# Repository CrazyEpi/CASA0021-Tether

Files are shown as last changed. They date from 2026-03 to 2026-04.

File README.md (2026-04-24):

# Tether 🚴

**A connected cycling companion for motivation, awareness and safety.**

Tether combines a handlebar-mounted ambient device with a companion mobile app to deliver real-time ride feedback, social comparison, and emergency signalling — without requiring cyclists to look at their phone.

<figure>
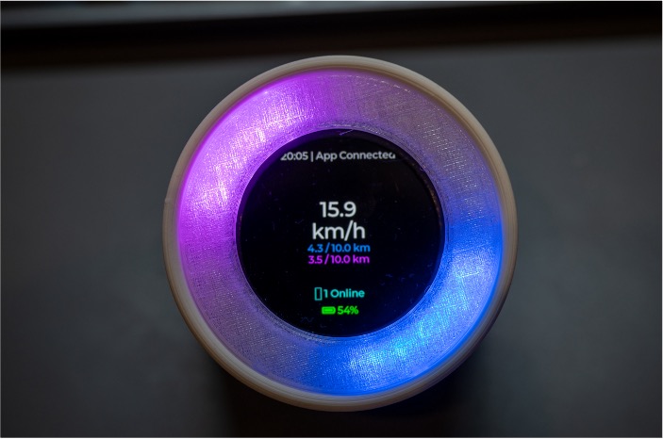
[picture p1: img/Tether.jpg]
Final Tether prototype mounted on handlebars
  
  <figcaption><strong>Figure 1.</strong> Final prototype mounted on handlebars, showing the 1.75" AMOLED display and 24-LED NeoPixel ring.</figcaption>
</figure>

---

## What does Tether do?

Tether solves a simple but important problem: cyclists need information that is easy to understand without becoming distracted. Existing apps like Strava require you to look at your phone. Cycling computers still demand focused attention. Tether moves that information to your handlebars in a form you can read in a glance.

The system has three core functions:

**Ride awareness** — The 24-LED NeoPixel ring fills progressively as you approach your distance goal. Speed, time, connection status and battery are shown on the AMOLED display. All feedback is designed to be readable peripherally, without stopping your ride.

**Social connection** — In friend mode, the LED ring splits into two arcs: blue for your progress, purple for your friend's. Both arcs update in real time via Firebase cloud sync, so you can feel connected to a riding partner even when riding separately.

**Safety signalling** — A three-second physical hold on the device button sends an SOS alert via BLE to the app and onwards to the cloud, notifying your contacts without you needing to unlock your phone.

---

## Why is Tether useful?

Most cycling technology is built around screen interaction — which is incompatible with the physical demands of riding. Tether is the only system we are aware of that combines ambient ride feedback, concurrent social presence, and physical emergency signalling in a single handlebar-mounted device.

Compared to the Beeline Velo 2 (£99.99) — the closest commercial comparator — Tether adds real-time friend comparison and active SOS signalling at a similar price point. The honest gap is battery durability and weather sealing, which are the primary targets for the next development cycle.

---

## Getting started

You will need:
- A compatible Android or iOS smartphone
- The Tether mobile app (Flutter)
- The assembled Tether hardware device
- Bluetooth enabled on your phone

### Phase 1 — Hardware assembly

**Components required:**

| Component | Purpose |
|---|---|
| Waveshare ESP32-S3-Touch-AMOLED-1.75 | Main controller + display |
| NeoPixel Ring — 24 x 5050 RGB LED | Ambient progress ring |
| 1000mAh 3.7V LiPo Battery | Power supply |
| 1.25mm Ultra-Slim 2-pin Cable | Battery connector |
| 3D-printed enclosure | Handlebar housing |

**3D-printed enclosure:**

The enclosure design file is included in the `/3dprint/` directory of this repository as a Fusion 360 file (`.f3d`). Open it in Autodesk Fusion 360 to export as STL before slicing. Print settings that worked for us:

- Material: PLA
- Layer height: 0.2mm
- Infill: 20%
- Supports: required for the internal nut holders

The enclosure went through four revision cycles. The current version (v4) includes a rotary interlock for handlebar attachment, a friction-based screen locker to prevent display rotation under vibration, and a diffuser cover over the LED ring. The handlebar mount uses rubber bands for rapid field adjustment during the prototype phase — loop them through the two side slots and around your handlebar.

**Assembly steps:**

1. Connect the 24-LED NeoPixel Ring to the ESP32-S3 board — Data pin to GPIO 16, with 3.3V/5V and GND connected appropriately.
2. Connect the battery to the board using the 1.25mm pitch 2-pin cable.
3. Seat all components inside the 3D-printed enclosure, matching the three copper nuts to the three holders. Insert the Dupont connector into the rectangular slot.
4. Attach the diffuser cover over the LED ring — press firmly to seat it evenly around the full circumference to minimise light bleed in direct sunlight.
5. Mount the enclosure to your handlebar using rubber bands through the side slots, or use the rotary interlock if your handlebar diameter is compatible.

> **Note:** The diffuser cover fit is intentionally tight — uneven seating causes light bleed between LED segments in bright conditions. This is a known limitation being addressed in the next enclosure revision.

### Phase 2 — ESP32 firmware setup (Arduino IDE)

**Board configuration:**

- Board: `ESP32S3 Dev Module`
- PSRAM: `OPI PSRAM` (enable in Tools menu if required by your board variant)

**Required libraries:**

| Library | Purpose |
|---|---|
| GFX_Library_for_Arduino | Graphics driver for the CO5300 display |
| ESP32_IO_Expander | Driver for the TCA9554 IO expansion chip |
| lvgl (v8.4.0) | Core LVGL graphics library |
| SensorLib | Driver for PCF85063, QMI8658, and CST9217 sensors |
| XPowersLib | Driver for the AXP2101 power management chip |
| Mylibrary | Custom macro definitions for development board pins |
| lv_conf.h | LVGL configuration file |

Install all libraries via Arduino IDE Library Manager or place them in your Arduino `libraries` folder. Flash the firmware to the ESP32-S3 via USB.

### Phase 3 — Mobile app setup (Flutter)

1. Ensure the Flutter SDK is installed on your machine ([flutter.dev](https://flutter.dev)).
2. Clone this repository and navigate to the `/app` directory.
3. Run `flutter pub get` to fetch all Dart package dependencies.
4. Connect your Android or iOS device and run `flutter run`.

The app will scan for the BLE device named `BikeTracker_E` automatically when you start a ride.

### Phase 4 — Firebase backend setup

Tether uses Firebase for three functions: user authentication, real-time ride data sync between riders, and managing each user's friend circle for social comparison and SOS contact routing.

**Services used:**
- **Firebase Authentication** — email/password sign-in for all app users
- **Cloud Firestore** — real-time database storing user profiles, ride data, and live ride state; used by the app's `onSnapshot` listeners to push a friend's updated distance to the handlebar device within seconds
- **Friend circle management** — each user document in Firestore stores a list of followed friends; the app queries this to populate the leaderboard, social feed, and live split-ring comparison

**Setup steps:**

1. Create a Firebase project at [console.firebase.google.com](https://console.firebase.google.com).
2. Enable **Firebase Authentication** (email/password provider).
3. Enable **Cloud Firestore** — select region `europe-west2`.
4. Download the `google-services.json` (Android) or `GoogleService-Info.plist` (iOS) from your Firebase project settings and place it in:
   - Android: `/app/android/app/google-services.json`
   - iOS: `/app/ios/Runner/GoogleService-Info.plist`
5. Apply the following Firestore security rules:

```
rules_version = '2';
service cloud.firestore {
  match /databases/{database}/documents {
    match /users/{userId} {
      allow read: if request.auth != null;
      allow write: if request.auth.uid == userId;
      match /{document=**} {
        allow read: if request.auth != null;
        allow write: if request.auth.uid == userId;
      }
    }
    match /rides/{rideId} {
      allow read, write: if request.auth != null;
    }
  }
}
```

6. Run `flutter pub get` after placing the config files, then rebuild the app.

> **Note:** The friend circle is managed through Firestore — users follow each other by storing friend UIDs in their user document. The app resolves friend live-ride state from Firestore in real time and writes it to the handlebar device via BLE on each update.

---

## BLE communication reference

The device and app communicate over a single BLE service.

**Device name:** `BikeTracker_E`  
**Primary service UUID:** `19B10000-E8F2-537E-4F6C-D104768A1214`

| Characteristic | UUID Suffix | Direction | Data type | Payload |
|---|---|---|---|---|
| Live Metrics | `...0001` | App → ESP32 | String (UTF-8) | `"Speed,MyDist,FriendDist,FriendGoal"` e.g. `15.5,2.5,3.1,10.0` |
| Target Goal | `...0002` | App → ESP32 | Float32 (LE) | Absolute target distance in km |
| Time Sync | `...0003` | App → ESP32 | String (UTF-8) | `"HH:MM"` — syncs phone time to display |
| Social State | `...0004` | App → ESP32 | Int32 (LE) | Number of online friends; triggers split-ring mode if > 0 |
| SOS Alert | `...0005` | ESP32 → App | Byte (Notify) | `0x01` triggered / `0x00` cleared |
| Social Pulse | `...0006` | App → ESP32 | Byte | `0x01` — triggers 2-second cyan breathing animation |

The SOS characteristic uses BLE Notify (device pushes to app) rather than polling, ensuring zero-latency emergency broadcast regardless of app foreground state.

---

## LED states reference

| Mode | Colour | Trigger |
|---|---|---|
| Solo riding | Single blue arc | No friends online |
| Friend mode | Split blue/purple arc | Friend online and riding |
| SOS emergency | Full ring solid red | SOS button held 3 seconds |
| Social pulse | Cyan breathing | Friend milestone event |
| Low speed | Dimmed display | Speed below threshold |

---

## App screens

The Flutter app covers the full ride lifecycle across 8 screens:

- **Home & feed** — activity feed, weekly stats, kudos
- **Live tracking** — real-time GPS map with BLE device connection
- **Goals & route planner** — set distance goals, plan route via Google Maps API
- **Leaderboard** — monthly and all-time rankings with friends
- **Profile** — ride history, stats, follow friends
- **Developer console** — simulate hardware LED states for testing without the physical device

---

## Where to get help

- **GitHub Issues** — [open an issue](../../issues) for bugs or technical problems
- **GitHub Discussions** — [start a discussion](../../discussions) for questions or ideas
- **Email** — contact the team directly at [ucfnuaw@ucl.ac.uk](mailto:ucfnuaw@ucl.ac.uk)

---

## Who maintains and contributes to this project

**Four Gods — Group 4, CASA0021, UCL Bartlett CASA 2025–26**

| Name | Role |
|---|---|
| Gilang Pamungkas | Backend & cloud infrastructure |
| Haoyu Hu | Hardware development, app improvement, testing, video |
| Yidan Gao | Frontend & mobile application |
| Yifei Huang | 3D print & enclosure design |

**Public repository:** [https://github.com/CrazyEpi/CASA0021-Tether](https://github.com/CrazyEpi/CASA0021-Tether)

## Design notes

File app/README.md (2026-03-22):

# GPP Cycling Tracker

UCL CASA0021 — Group 3 · Flutter App

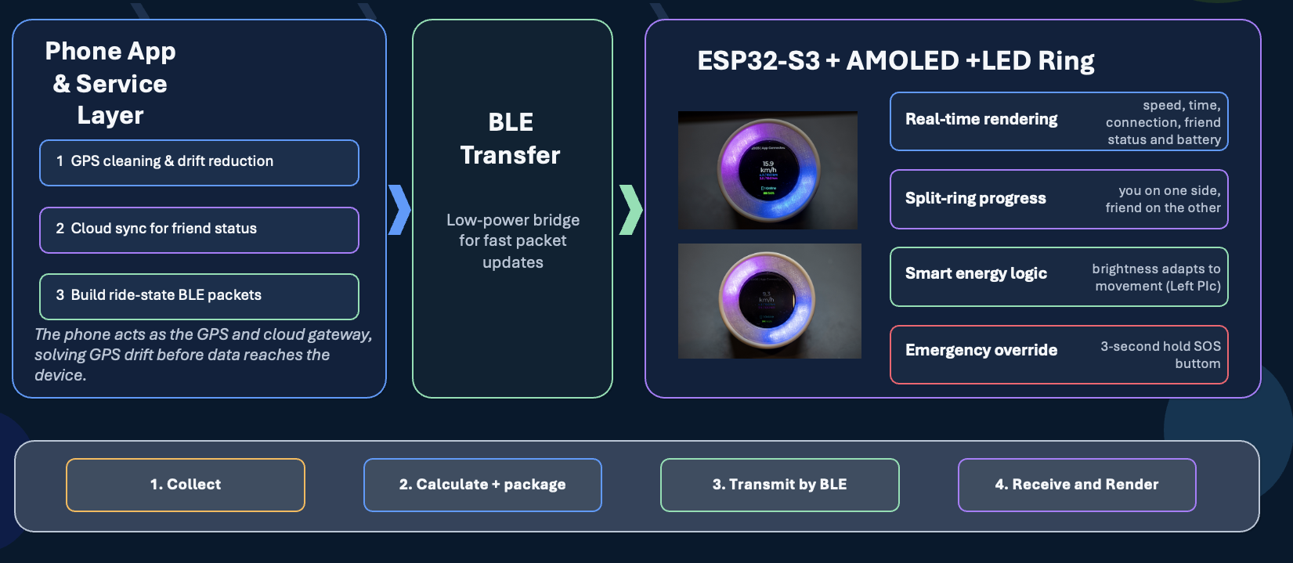
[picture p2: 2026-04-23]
img/diagram.png

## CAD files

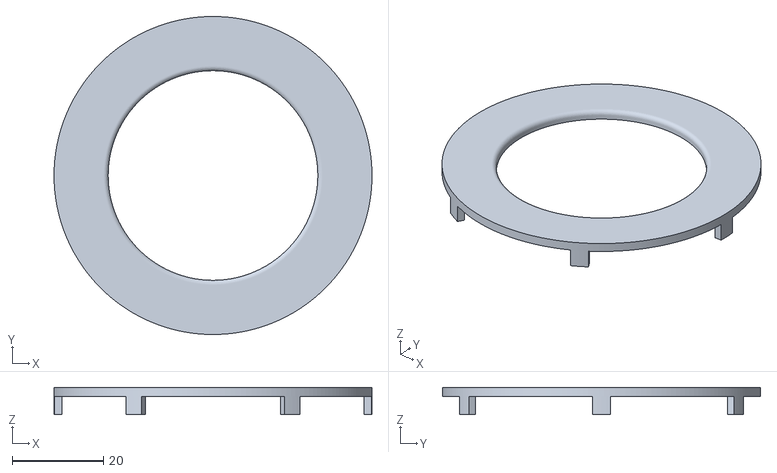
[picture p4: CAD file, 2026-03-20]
3dprint/3Dprint/top.stl
69.8 x 69.8 x 6.00

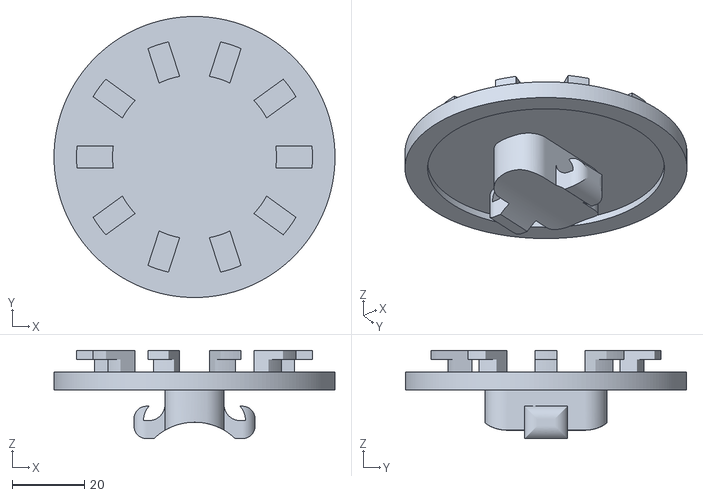
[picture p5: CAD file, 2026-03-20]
3dprint/3dPrint3/bottom.stl
78.0 x 78.0 x 24.5

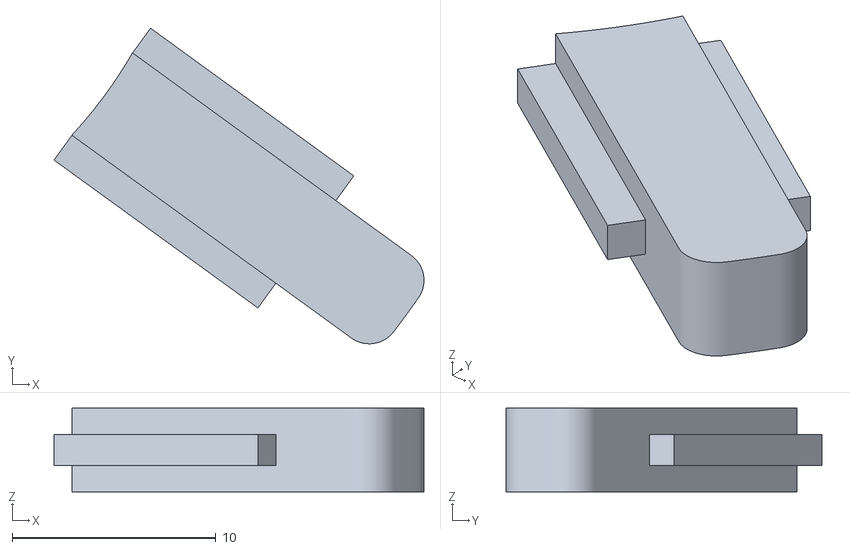
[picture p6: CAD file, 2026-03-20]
3dprint/3dPrint4/buttonLong.stl
18.2 x 15.5 x 4.10

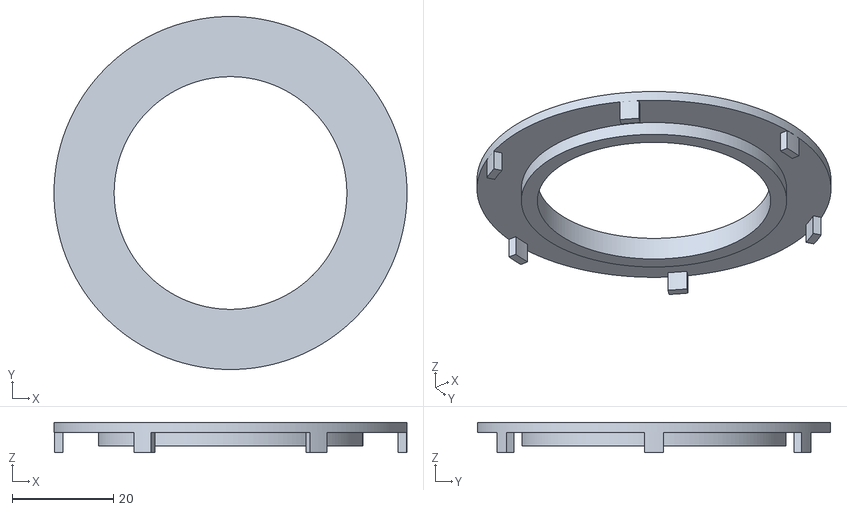
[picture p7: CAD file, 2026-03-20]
3dprint/3dPrint5/top.stl
69.8 x 69.8 x 6.00

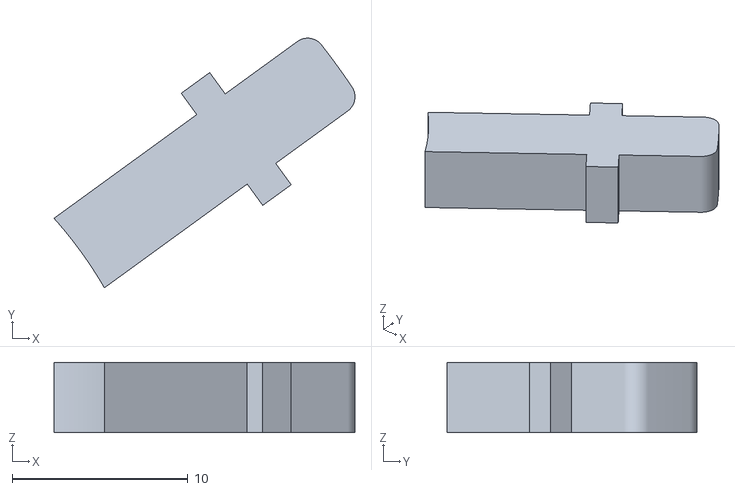
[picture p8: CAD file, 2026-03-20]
3dprint/3Dprint/b.stl
17.1 x 14.2 x 4.00

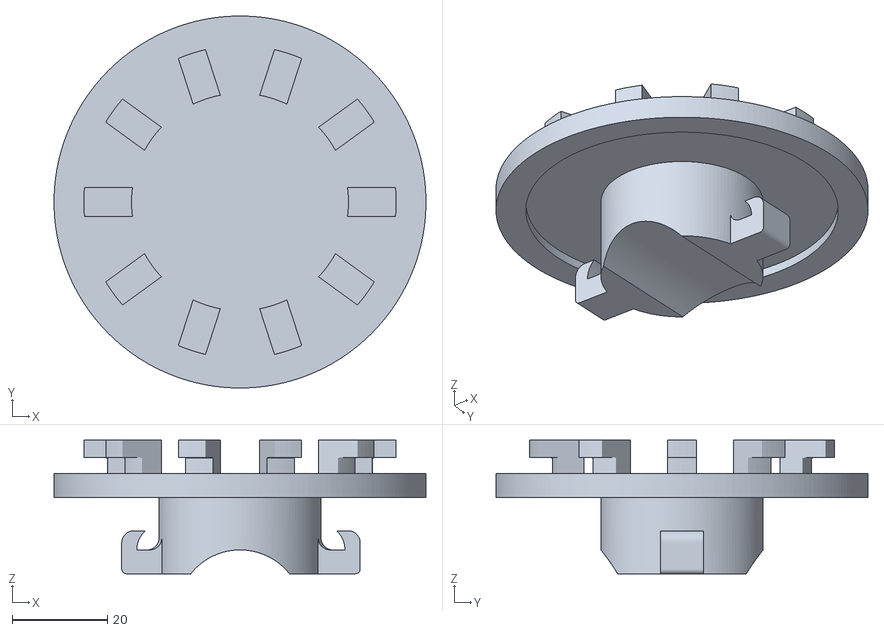
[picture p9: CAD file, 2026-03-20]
3dprint/3dprint2/bottom2.stl
78.0 x 78.0 x 28.0

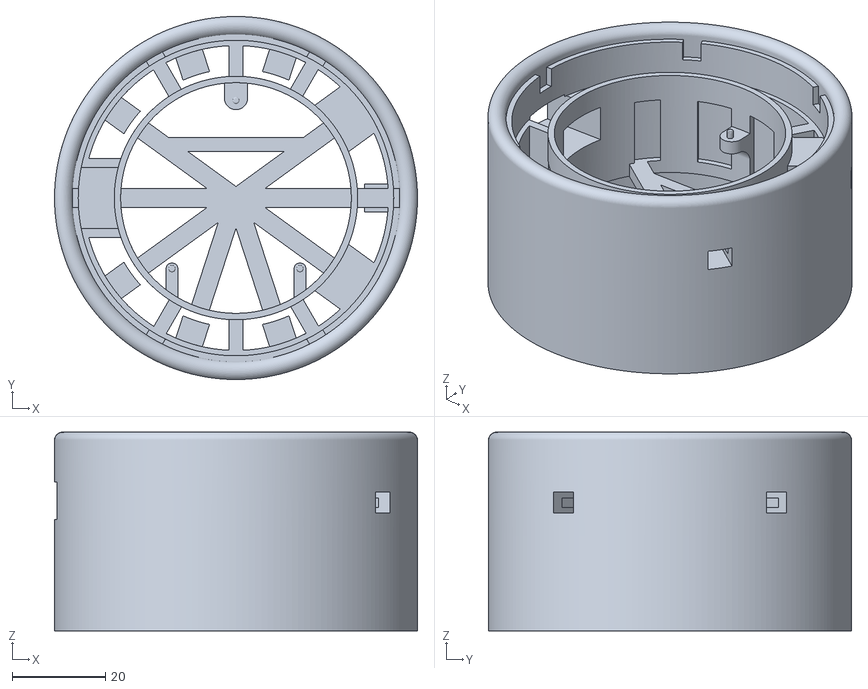
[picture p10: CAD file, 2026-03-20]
3dprint/3dPrint3/case.stl
78.0 x 78.0 x 42.8

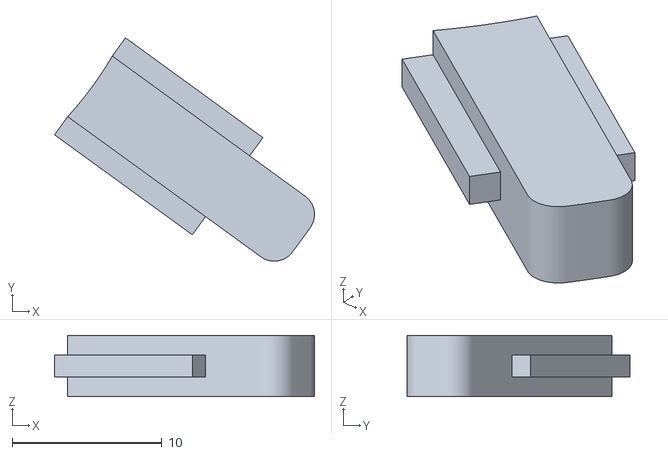
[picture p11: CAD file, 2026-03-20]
3dprint/3dPrint4/button.stl
17.3 x 14.9 x 4.10

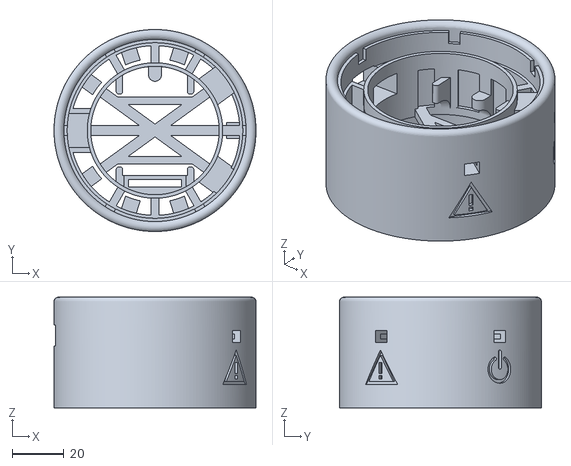
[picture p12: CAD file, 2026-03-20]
3dprint/3dPrint5/case.stl
78.0 x 78.0 x 42.8

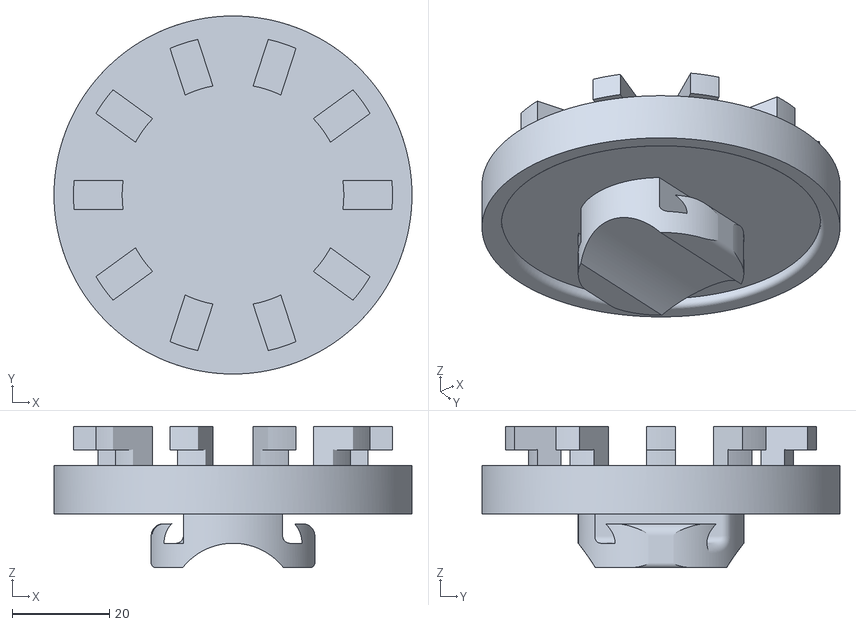
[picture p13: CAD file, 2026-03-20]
3dprint/3Dprint/bottom.stl
73.5 x 73.5 x 29.0

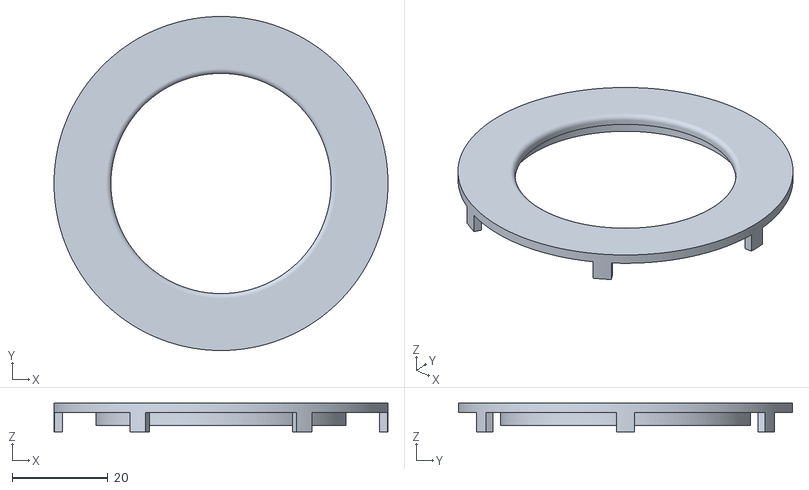
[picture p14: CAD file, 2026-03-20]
3dprint/3dPrint3/top.stl
69.8 x 69.8 x 6.00

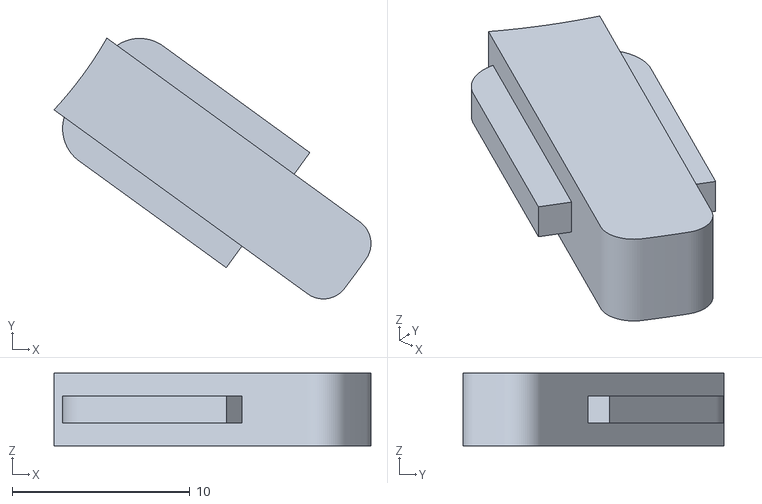
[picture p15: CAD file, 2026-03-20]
3dprint/3dPrint5/button.stl
17.8 x 14.7 x 4.10

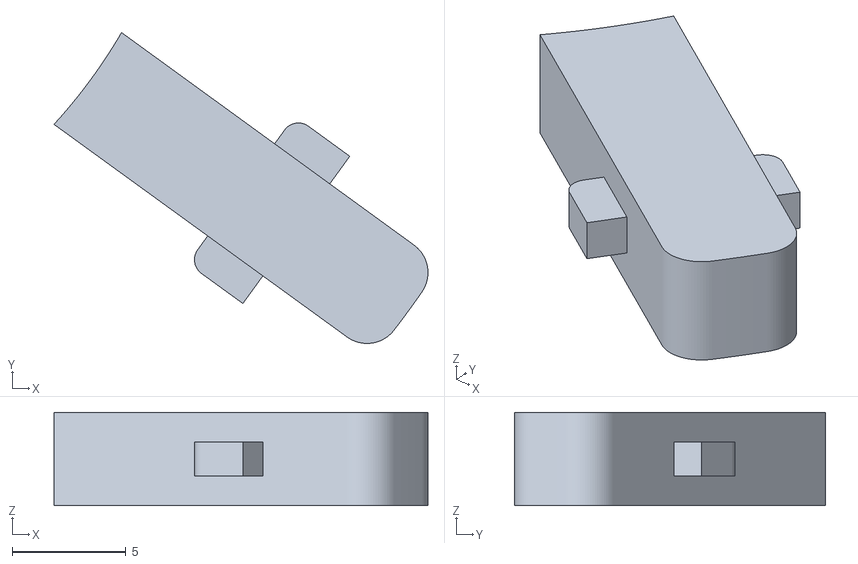
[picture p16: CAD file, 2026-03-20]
3dprint/3dPrint3/button.stl
16.5 x 13.7 x 4.10

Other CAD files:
3dprint/3dprint2/top.stl
3dprint/3dPrint4/case.stl
3dprint/3Dprint/bottomBIG.stl
3dprint/3dprint2/case.stl
3dprint/0021-EnclosurePrototypeTwo.f3d
3dprint/3Dprint/a.stl
3dprint/3Dprint/c.stl
3dprint/3Dprint/case.stl
3dprint/3Dprint/d.stl
3dprint/3Dprint/firstprint.3mf
3dprint/3dPrint5/0021-EnclosurePrototypeFive.f3d.f3d
3dprint/3dPrint5/bottom.stl
3dprint/3dprint2/button.stl
3dprint/CASA0021.f3d

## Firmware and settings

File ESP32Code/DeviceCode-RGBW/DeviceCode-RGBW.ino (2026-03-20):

#include <ArduinoBLE.h>
#include <Adafruit_NeoPixel.h>
#include <lvgl.h>
#include "Arduino_GFX_Library.h"
#include "pin_config.h" 
#include <Wire.h>
#include "XPowersLib.h"
#include "TouchDrvCSTXXX.hpp" 

// Pin Config
#define LED_PIN    16   
#define NUMPIXELS  24   // 24 LED Ring
#define BOOT_PIN   0

// RGBW LED Ring
Adafruit_NeoPixel pixels(NUMPIXELS, LED_PIN, NEO_GRBW + NEO_KHZ800);
XPowersPMU power;
TouchDrvCST92xx touch;

Arduino_DataBus *bus = new Arduino_ESP32QSPI(LCD_CS, LCD_SCLK, LCD_SDIO0, LCD_SDIO1, LCD_SDIO2, LCD_SDIO3);
Arduino_CO5300 *gfx = new Arduino_CO5300(bus, LCD_RESET, 0, LCD_WIDTH, LCD_HEIGHT, 6, 0, 0, 0);

static lv_disp_draw_buf_t draw_buf;
static lv_color_t buf[LCD_WIDTH * LCD_HEIGHT / 10];

// Bluetooth "Service" and "Characteristic" UUID
// Service ID: bluetooth function id for connection
// Characteristic ID: detailed function id for functions like location update
const char* BLE_SERVICE_UUID       = "19B10000-E8F2-537E-4F6C-D104768A1214";
const char* BLE_LOCATION_CHAR_UUID = "19B10001-E8F2-537E-4F6C-D104768A1214"; 
const char* BLE_GOAL_CHAR_UUID     = "19B10002-E8F2-537E-4F6C-D104768A1214"; 
const char* BLE_TIME_CHAR_UUID     = "19B10003-E8F2-537E-4F6C-D104768A1214"; 
const char* BLE_FRIEND_CHAR_UUID   = "19B10004-E8F2-537E-4F6C-D104768A1214"; 
const char* BLE_SOS_CHAR_UUID      = "19B10005-E8F2-537E-4F6C-D104768A1214";
const char* BLE_SOCIAL_CHAR_UUID   = "19B10006-E8F2-537E-4F6C-D104768A1214"; 

BLEService bikeService(BLE_SERVICE_UUID);
BLEStringCharacteristic locationChar(BLE_LOCATION_CHAR_UUID, BLERead | BLEWrite, 64); 
BLEFloatCharacteristic goalChar(BLE_GOAL_CHAR_UUID, BLERead | BLEWrite); 
BLEStringCharacteristic timeChar(BLE_TIME_CHAR_UUID, BLERead | BLEWrite, 10);
BLEIntCharacteristic friendChar(BLE_FRIEND_CHAR_UUID, BLERead | BLEWrite);
BLEByteCharacteristic sosChar(BLE_SOS_CHAR_UUID, BLERead | BLENotify);
BLEByteCharacteristic socialChar(BLE_SOCIAL_CHAR_UUID, BLERead | BLEWrite); 

// default datas
double totalDistanceKm = 0.0;
double targetDistanceKm = 10.0; 
float currentSpeed = 0.0;

double friendDistanceKm = 0.0; 
double friendGoalKm = 10.0;     
float friendProgress = 0.0;     

int onlineFriends = 0;
char currentTime[16] = "--:--"; 
bool isPhoneConnected = false;
unsigned long connectionTimestamp = 0;

bool isScreenOn = true;
bool isEmergency = false;
uint8_t currentScreenBrightness = 90;
int16_t touch_x[5], touch_y[5];

bool isSocialPulsing = false;
unsigned long socialPulseTimestamp = 0;

// LVGL UI Stuff
lv_obj_t *label_speed, *label_dist, *label_gps, *label_friends, *label_battery, *sos_container;

// Screen Renderer
void my_disp_flush(lv_disp_drv_t *disp, const lv_area_t *area, lv_color_t *color_p) {
  uint32_t w = (area->x2 - area->x1 + 1); uint32_t h = (area->y2 - area->y1 + 1);
#if (LV_COLOR_16_SWAP != 0)
  gfx->draw16bitBeRGBBitmap(area->x1, area->y1, (uint16_t *)&color_p->full, w, h);
#else
  gfx->draw16bitRGBBitmap(area->x1, area->y1, (uint16_t *)&color_p->full, w, h);
#endif
  lv_disp_flush_ready(disp);
}

// Touchpad read
void my_touchpad_read(lv_indev_drv_t *indev_driver, lv_indev_data_t *data) {
  uint8_t touched = touch.getPoint(touch_x, touch_y, touch.getSupportTouchPoint());
  if (touched > 0) {
    data->state = LV_INDEV_STATE_PR;
    data->point.x = touch_x[0]; data->point.y = touch_y[0];
  } else {
    data->state = LV_INDEV_STATE_REL;
  }
}

// timer for LVGL refresh
void example_increase_lvgl_tick(void *arg) { lv_tick_inc(2); }

// SOS long press cancel
void sos_clear_event_cb(lv_event_t * e) {
  if (isEmergency) {
    isEmergency = false;
    lv_obj_add_flag(sos_container, LV_OBJ_FLAG_HIDDEN);
    sosChar.writeValue((uint8_t)0);
  }
}

// Initialize UI components
void init_bike_dashboard() {
  lv_obj_set_style_bg_color(lv_scr_act(), lv_color_hex(0x000000), LV_PART_MAIN);

  // speed
  label_speed = lv_label_create(lv_scr_act());
  lv_obj_set_width(label_speed, 300); 
  lv_obj_set_style_text_color(label_speed, lv_color_hex(0xFFFFFF), LV_PART_MAIN);
  lv_obj_set_style_text_font(label_speed, &lv_font_montserrat_48, LV_PART_MAIN); 
  lv_label_set_text(label_speed, "0.0\nkm/h");
  lv_obj_set_style_text_align(label_speed, LV_TEXT_ALIGN_CENTER, LV_PART_MAIN);
  lv_obj_align(label_speed, LV_ALIGN_CENTER, 0, -35); 

  // distance multi-color
  label_dist = lv_label_create(lv_scr_act());
  lv_obj_set_width(label_dist, 300); 
  lv_label_set_recolor(label_dist, true); 
  lv_obj_set_style_text_font(label_dist, &lv_font_montserrat_24, LV_PART_MAIN); 
  lv_label_set_text(label_dist, "#4A90E2 0.0 / 0.0 km#"); 
  lv_obj_set_style_text_align(label_dist, LV_TEXT_ALIGN_CENTER, LV_PART_MAIN);
  lv_obj_align(label_dist, LV_ALIGN_CENTER, 0, 45); 

  // Time + App Status
  label_gps = lv_label_create(lv_scr_act());
  lv_obj_set_width(label_gps, 300); 
  lv_obj_set_style_text_color(label_gps, lv_color_hex(0xAAAAAA), LV_PART_MAIN);
  lv_obj_set_style_text_font(label_gps, &lv_font_montserrat_24, LV_PART_MAIN);
  lv_label_set_text(label_gps, "--:-- | Waiting...");
  lv_obj_set_style_text_align(label_gps, LV_TEXT_ALIGN_CENTER, LV_PART_MAIN);
  lv_obj_align(label_gps, LV_ALIGN_TOP_MID, 0, 30); 

  // Friend Status
  label_friends = lv_label_create(lv_scr_act());
  lv_obj_set_width(label_friends, 300); 
  lv_obj_set_style_text_color(label_friends, lv_color_hex(0x00FFFF), LV_PART_MAIN);
  lv_obj_set_style_text_font(label_friends, &lv_font_montserrat_24, LV_PART_MAIN);
  lv_label_set_text(label_friends, ""); 
  lv_obj_set_style_text_align(label_friends, LV_TEXT_ALIGN_CENTER, LV_PART_MAIN);
  lv_obj_align(label_friends, LV_ALIGN_BOTTOM_MID, 0, -80);
  
  // Battery Info
  label_battery = lv_label_create(lv_scr_act());
  lv_obj_set_width(label_battery, 200); 
  lv_obj_set_style_text_color(label_battery, lv_color_hex(0x00FF00), LV_PART_MAIN);
  lv_obj_set_style_text_font(label_battery, &lv_font_montserrat_24, LV_PART_MAIN);
  lv_label_set_text(label_battery, LV_SYMBOL_BATTERY_FULL " --%");
  lv_obj_set_style_text_align(label_battery, LV_TEXT_ALIGN_CENTER, LV_PART_MAIN);
  lv_obj_align(label_battery, LV_ALIGN_BOTTOM_MID, 0, -40);

  // SOS Red Screen
  sos_container = lv_obj_create(lv_scr_act());
  lv_obj_set_size(sos_container, LCD_WIDTH, LCD_HEIGHT);
  lv_obj_set_style_bg_color(sos_container, lv_color_hex(0xAA0000), 0);
  lv_obj_set_style_border_width(sos_container, 0, 0);
  lv_obj_align(sos_container, LV_ALIGN_CENTER, 0, 0);
  lv_obj_add_flag(sos_container, LV_OBJ_FLAG_CLICKABLE);
  lv_obj_add_flag(sos_container, LV_OBJ_FLAG_HIDDEN);
  lv_obj_add_event_cb(sos_container, sos_clear_event_cb, LV_EVENT_LONG_PRESSED, NULL);

  lv_obj_t *sos_label = lv_label_create(sos_container);
  lv_obj_set_style_text_color(sos_label, lv_color_hex(0xFFFFFF), 0);
  lv_obj_set_style_text_font(sos_label, &lv_font_montserrat_48, 0);
  lv_label_set_text(sos_label, LV_SYMBOL_WARNING "\nSOS");
  lv_obj_set_style_text_align(sos_label, LV_TEXT_ALIGN_CENTER, 0);
  lv_obj_align(sos_label, LV_ALIGN_CENTER, 0, 0);
}

void setup() {
  Serial.begin(115200);
  unsigned long startWait = millis();
  while (!Serial && millis() - startWait < 3000) { delay(10); }

  pinMode(BOOT_PIN, INPUT_PULLUP);

  Wire.begin(IIC_SDA, IIC_SCL);
  if(power.begin(Wire, AXP2101_SLAVE_ADDRESS, IIC_SDA, IIC_SCL)) {
    // Initialize Battery Control
    power.clearIrqStatus(); 
    power.enableBattVoltageMeasure();
    power.enableVbusVoltageMeasure(); 
    power.enableIRQ(XPOWERS_AXP2101_PKEY_SHORT_IRQ); 
  }

  touch.setPins(TP_RESET, TP_INT);
  touch.begin(Wire, 0x5A, IIC_SDA, IIC_SCL);
  touch.setMaxCoordinates(LCD_WIDTH, LCD_HEIGHT);
  touch.setMirrorXY(true, true);

  // Display Setups
  gfx->begin();
  gfx->setBrightness(currentScreenBrightness);
  lv_init();
  lv_disp_draw_buf_init(&draw_buf, buf, NULL, LCD_WIDTH * LCD_HEIGHT / 10);
  
  static lv_disp_drv_t disp_drv;
  lv_disp_drv_init(&disp_drv);
  disp_drv.hor_res = LCD_WIDTH; disp_drv.ver_res = LCD_HEIGHT;
  disp_drv.flush_cb = my_disp_flush; disp_drv.draw_buf = &draw_buf;
  lv_disp_drv_register(&disp_drv);

  static lv_indev_drv_t indev_drv;
  lv_indev_drv_init(&indev_drv);
  indev_drv.type = LV_INDEV_TYPE_POINTER;
  indev_drv.read_cb = my_touchpad_read;
  lv_indev_drv_register(&indev_drv);

  // Start the timer
  const esp_timer_create_args_t lvgl_tick_timer_args = { .callback = &example_increase_lvgl_tick, .name = "lvgl_tick" };
  esp_timer_handle_t lvgl_tick_timer = NULL;
  esp_timer_create(&lvgl_tick_timer_args, &lvgl_tick_timer);
  esp_timer_start_periodic(lvgl_tick_timer, 2000); // 2ms tick

  init_bike_dashboard();
  
  // NeoPixel Settings
  pixels.begin(); pixels.setBrightness(25); pixels.clear(); pixels.show();
  
  // Delay for battery then start bluetooth
  delay(300); 

  if (!BLE.begin()) { while (1); }
  BLE.setLocalName("BikeTracker_E"); 
  BLE.setAdvertisedService(bikeService);
  bikeService.addCharacteristic(locationChar);
  bikeService.addCharacteristic(goalChar);
  bikeService.addCharacteristic(timeChar);
  bikeService.addCharacteristic(friendChar);
  bikeService.addCharacteristic(sosChar); 
  bikeService.addCharacteristic(socialChar);
  BLE.addService(bikeService);
  
  sosChar.writeValue((uint8_t)0); 
  BLE.advertise();
}

void loop() {
  BLEDevice central = BLE.central();
  
  // power button screen off
  power.getIrqStatus();
  if (power.isPekeyShortPressIrq()) {
    isScreenOn = !isScreenOn;
    gfx->setBrightness(isScreenOn ? currentScreenBrightness : 0);
    power.clearIrqStatus();
  }

  // Boot long press SOS
  static unsigned long bootPressTime = 0;
  static bool bootPressed = false;
  
  if (digitalRead(BOOT_PIN) == LOW) {
    if (!bootPressed) {
      bootPressed = true;
      bootPressTime = millis();
    } else {
      if (millis() - bootPressTime > 3000 && !isEmergency) {
        isEmergency = true;
        lv_obj_clear_flag(sos_container, LV_OBJ_FLAG_HIDDEN);
        sosChar.writeValue((uint8_t)1); 
        if (!isScreenOn) { isScreenOn = true; gfx->setBrightness(currentScreenBrightness); }
      }
    }
  } else {
    if (bootPressed) {
      unsigned long pressDuration = millis() - bootPressTime;
      if (isEmergency && pressDuration < 1000) {
        isEmergency = false;
        lv_obj_add_flag(sos_container, LV_OBJ_FLAG_HIDDEN);
        sosChar.writeValue((uint8_t)0);
      }
      bootPressed = false;
    }
  }

  // handle data from app
  if (central && central.connected()) {
    if (!isPhoneConnected) {
      isPhoneConnected = true;
      connectionTimestamp = millis();
    }

    // Sync Distance
    if (goalChar.written()) targetDistanceKm = goalChar.value();
    
    // Sync Time
    if (timeChar.written()) {
      String tStr = timeChar.value(); tStr.trim(); 
      strncpy(currentTime, tStr.c_str(), sizeof(currentTime) - 1);
      currentTime[sizeof(currentTime) - 1] = '\0'; 
    }
    
    // Sync friend number
    if (friendChar.written()) {
      onlineFriends = friendChar.value();
      if (onlineFriends > 0) {
        static char friends_buf[32]; 
        snprintf(friends_buf, sizeof(friends_buf), "👥 %d Online", onlineFriends);
        lv_label_set_text(label_friends, friends_buf);
      } else {
        lv_label_set_text(label_friends, ""); 
      }
    }

    // Parse riding data
    if (locationChar.written()) {
      String locStr = locationChar.value();
      locStr.trim(); 
      
      int c1 = locStr.indexOf(',');
      int c2 = locStr.indexOf(',', c1 + 1);
      int c3 = locStr.indexOf(',', c2 + 1);
      
      if (c1 > 0) {
        currentSpeed = locStr.substring(0, c1).toFloat();
        if (c2 > 0) {
           if (c3 > 0) {
               totalDistanceKm = locStr.substring(c1 + 1, c2).toFloat();
               friendDistanceKm = locStr.substring(c2 + 1, c3).toFloat();
               friendGoalKm = locStr.substring(c3 + 1).toFloat();
               if(friendGoalKm <= 0.1) friendGoalKm = 10.0; 
               friendProgress = friendDistanceKm / friendGoalKm;
           } else {
               totalDistanceKm = locStr.substring(c1 + 1, c2).toFloat();
               friendProgress = locStr.substring(c2 + 1).toFloat();
           }
        } else {
           totalDistanceKm = locStr.substring(c1 + 1).toFloat();
        }
      }
    }

    // Sync social pulse
    if (socialChar.written()) {
      if (socialChar.value() == 0x01) {
        isSocialPulsing = true;
        socialPulseTimestamp = millis();
      }
    }

  } else {
    isPhoneConnected = false;
    currentSpeed = 0.0;
  }

  // UI refresh 10hz
  static unsigned long lastUIUpdate = 0;
  if (millis() - lastUIUpdate > 100) {
    lastUIUpdate = millis();

    static char bat_buf[32];
    static char gps_buf[32];
    static char speed_buf[16];
    static char dist_buf[128]; 

    // Auto brightness
    uint8_t targetBrightness = (currentSpeed >= 10.0) ? 200 : 40; 
    uint8_t ledBrightness = (currentSpeed >= 10.0) ? 50 : 20; 

    if (isScreenOn && currentScreenBrightness != targetBrightness) {
      currentScreenBrightness = targetBrightness;
      gfx->setBrightness(currentScreenBrightness);
    }
    pixels.setBrightness(ledBrightness);

    // Update Battery Percentage
    const char* pwr_icon = LV_SYMBOL_BATTERY_FULL; 
    if (power.isVbusIn()) {
      pwr_icon = power.isCharging() ? LV_SYMBOL_CHARGE : LV_SYMBOL_USB; 
    }

    if (power.isBatteryConnect()) {
      snprintf(bat_buf, sizeof(bat_buf), "%s %d%%", pwr_icon, power.getBatteryPercent());
    } else {
      snprintf(bat_buf, sizeof(bat_buf), "%s NO BAT", pwr_icon);
    }
    lv_label_set_text(label_battery, bat_buf);

    if (isPhoneConnected) {
      snprintf(gps_buf, sizeof(gps_buf), "%s | App Connected", currentTime);
      lv_label_set_text(label_gps, gps_buf);
      
      snprintf(speed_buf, sizeof(speed_buf), "%.1f\nkm/h", currentSpeed);
      lv_label_set_text(label_speed, speed_buf);

      if (onlineFriends == 0) {
        snprintf(dist_buf, sizeof(dist_buf), "#4A90E2 %.1f / %.1f km#", totalDistanceKm, targetDistanceKm);
      } else {
        snprintf(dist_buf, sizeof(dist_buf), "#4A90E2 %.1f / %.1f km#\n#D142F5 %.1f / %.1f km#", 
                 totalDistanceKm, targetDistanceKm, friendDistanceKm, friendGoalKm);
      }
      lv_label_set_text(label_dist, dist_buf);

    } else {
      snprintf(gps_buf, sizeof(gps_buf), "%s | Waiting App...", currentTime);
      lv_label_set_text(label_gps, gps_buf);
      lv_label_set_text(label_speed, "0.0\nkm/h");
      lv_label_set_text(label_dist, "#4A90E2 0.0 / 0.0 km#");
    }
    
    // Light Control Router
    if (isEmergency) {
       if ((millis() / 300) % 2 == 0) pixels.fill(pixels.Color(200, 0, 0, 0));
       else pixels.clear();
       pixels.show();
    } 
    else if (isSocialPulsing) {
       if (millis() - socialPulseTimestamp < 2000) updateLED_Social_Pulse();
       else isSocialPulsing = false; 
    }
    else if (isPhoneConnected) {
       if (millis() - connectionTimestamp < 3000) {
         pixels.fill(pixels.Color(0, 150, 0, 0)); pixels.show();
       } else {
         updateLED_SmartProgress(); 
       }
    } 
    else {
       updateLED_Searching_Yellow();
    }
  }

  lv_timer_handler(); 
  delay(5);
}

// Light Control
void updateLED_SmartProgress() {
  float myProg = totalDistanceKm / targetDistanceKm;
  if (myProg > 1.0) myProg = 1.0;
  if (myProg < 0.0) myProg = 0.0;

  pixels.clear();

  if (onlineFriends == 0) {
    int ledsToLight = round(myProg * NUMPIXELS);
    for (int i = 0; i < NUMPIXELS; i++) {
      if (i < ledsToLight) pixels.setPixelColor(i, pixels.Color(0, 0, 150, 0));
    }
  } else {
    float frProg = friendProgress;
    if (frProg > 1.0) frProg = 1.0;
    if (frProg < 0.0) frProg = 0.0;

    int halfLeds = NUMPIXELS / 2; // 12
    int myLedsToLight = round(myProg * halfLeds);
    int frLedsToLight = round(frProg * halfLeds);

    for (int i = 0; i < halfLeds; i++) {
      if (i < myLedsToLight) pixels.setPixelColor(i, pixels.Color(0, 0, 150, 0));
    }
    for (int i = 0; i < halfLeds; i++) {
      if (i < frLedsToLight) pixels.setPixelColor(i + halfLeds, pixels.Color(150, 0, 150, 0));
    }
  }
  
  pixels.show(); 
}

void updateLED_Searching_Yellow() {
  pixels.fill(pixels.Color(100, 100, 0, 0)); pixels.show();
}

void updateLED_Social_Pulse() {
  unsigned long t = millis() - socialPulseTimestamp;
  float breath = (sin(t / 150.0) + 1.0) / 2.0; 
  uint8_t brightness = 20 + (breath * 80);
  int offset = (t / 50) % NUMPIXELS;

  pixels.clear();
  for (int i = 0; i < NUMPIXELS; i++) {
    if (i == offset || i == (offset + NUMPIXELS/2) % NUMPIXELS) {
      pixels.setPixelColor(i, pixels.Color(0, 0, 0, 0));
    } else {
      pixels.setPixelColor(i, pixels.Color(0, brightness, brightness, 0));
    }
  }
  pixels.show();
}

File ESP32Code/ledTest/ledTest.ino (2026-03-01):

#include <Adafruit_NeoPixel.h>

// LED Settings
#define LED_PIN    6   // LED Pin: 6
#define NUMPIXELS  12  // LED numbers
Adafruit_NeoPixel pixels(NUMPIXELS, LED_PIN, NEO_GRB + NEO_KHZ800);

float targetDistance = 100.0;
float currentDistance = 0.0;

void setup() {
  // baud rate: DO NOT SET TO 9600, it wont work
  Serial.begin(115200);
  while (!Serial) { delay(10); }

  // initialize led
  pixels.begin();
  pixels.clear();
  pixels.show();

  Serial.println("\n=================================");
  Serial.println("LED TEST !!!!!!!!");
  Serial.println("=================================");
  Serial.println("Send command to mimic user scene");
  Serial.println("Input: T+Number = target distance (T100 = 100m)");
  Serial.println("Input D+Number = current distance (D80 = now went 80m)");
  Serial.println("=================================\n");
  
  updateLEDProgress();
}

void loop() {
  if (Serial.available() > 0) {
    String input = Serial.readStringUntil('\n');

    if (input.length() > 1) {
      // take command type
      char command = input.charAt(0);
      float value = input.substring(1).toFloat();

      if (command == 'T' || command == 't') {
        if (value <= 0) {
          Serial.println("distance must > 0");
        } else {
          targetDistance = value;
          Serial.print("target update : ");
          Serial.print(targetDistance);
          Serial.println(" m");
        }
      } 
      else if (command == 'D' || command == 'd') {
        currentDistance = value;
        Serial.print("current distance update: ");
        Serial.print(currentDistance);
        Serial.println(" m");
      } 
      else {
        Serial.println("Unknown command ");
      }

      // update led
      updateLEDProgress();
    }
  }
}

// light control
void updateLEDProgress() {
  // percentage
  float progress = currentDistance / targetDistance;
  
  // frame boundries
  if (progress < 0) progress = 0;
  if (progress > 1.0) progress = 1.0; 

  // lighted led numbers
  int ledsToLight = round(progress * NUMPIXELS);

  Serial.print("Current Progress: ");
  Serial.print(progress * 100, 1);
  Serial.print("%  |  Lighted LED Numbers: ");
  Serial.print(ledsToLight);
  Serial.print(" / ");
  Serial.println(NUMPIXELS);
  Serial.println("---------------------------------");

  // update LED
  pixels.clear();
  for (int i = 0; i < NUMPIXELS; i++) {
    if (i < ledsToLight) {
      // Gree: finished parts
      pixels.setPixelColor(i, pixels.Color(0, 100, 0));
    } else {
      // unfinished parts
      pixels.setPixelColor(i, pixels.Color(0, 0, 0)); 
    }
  }
  pixels.show();
}

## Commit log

2026-03-01 first prototype, no led function
    device take in location, calculate data, send to app
2026-03-01 led functions test file
    no gps or app functions
2026-03-02 Add BLE goal, GPS distance tracking & LEDs
    update led function, bluetooth functions.
    Take goal from mobile app
2026-03-05 Add App.framework binary
2026-03-05 Add build: Debug frameworks (FlutterMacOS, shared_prefs, etc)
2026-03-05 Add build: Debug App.framework
2026-03-05 Create print1
2026-03-06 update json on arduino code
2026-03-09 proof of concept data flow from sensor to live tracking app to firebase
2026-03-16 debug-display error
    debug-display error
    [DeviceCode.ino]
2026-03-17 debug- device font fracture
    debug- device font fracture
2026-03-17 Add 3D print weight to README
2026-03-18 fixing user and ble sync
    [DeviceCode.ino]
2026-03-18 sync data between two device
2026-03-20 Add RGBW code and UI/LED updates
    Introduce DeviceCode-RGBW.ino for RGBW NeoPixel support and new LED patterns. Update DeviceCode.ino to achieve feature parity, adding BLE social features, LVGL UI enhancements, and improved power man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
2026-03-20 history enclosure iteration files
    history enclosure iteration files
    [0021-EnclosurePrototypeFive.f3d.f3d, a.stl, b.stl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]
2026-03-21 added emergency boardcast
2026-03-22 Enhance README with setup and configuration details
    Added detailed setup instructions for hardware assembly, ESP32 firmware setup, and Flutter app environment.
2026-03-23 Update README with BLE device specifications
    Added detailed BLE characteristics and device information.
2026-04-23 Add problem statement to README
    Added a problem statement outlining the limitations of current cycling interfaces and the need for better integration of awareness, motivation, safety, and social connection during cycling.
2026-04-23 Revise problem context and motivation in README
    Updated the problem identification section to reflect a broader context of mobility and interaction challenges. Enhanced clarity on the limitations of current cycling interfaces and introduced the concept of ambient interaction models.
2026-04-23 Add problem statement section to README
    Added a problem statement section to outline the limitations of current cycling interfaces and technologies in relation to user experience and safety.
2026-04-23 Refine problem context and motivation for cycling interfaces
    Revised the problem context and motivation sections to clarify the limitations of current cycling interfaces and the need for low-attention interaction models. Enhanced the focus on social and affective dimensions in cycling technology.
